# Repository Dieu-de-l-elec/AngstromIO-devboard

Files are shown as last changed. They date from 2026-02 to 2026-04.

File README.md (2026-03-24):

# AngstromIO-devboard

AngstromIO is one of the smallest devboards out there, barely longer than a USB-C connector, based on the Attiny1616 MCU. 2 GPIOs as well as I2C lines are broken out. 
I made a dual CH340 programming board too, both for UPDI programming and debugging (one way Serial Communication). 
I also designed a breadboard friendly, experimentation board for the CH32V003, with a 5x4 charlieplexed LED matrix.

While the AngstromIO is a tiny devboard, yet powerful, that could be embedded in any space constrained projects, the CH32 devboard is more an experimentation board, for me to learn how to program this awesome chip on the MounriverStudio programming and how to program a charlieplexed matrix. The Programmer is an all in one module, that will make debugging with the Serial monitor while programming easy: one board for both.

<br><br>
<p align="center">
  Project Banner
  AIO demo gif
</p>
<p align="center">
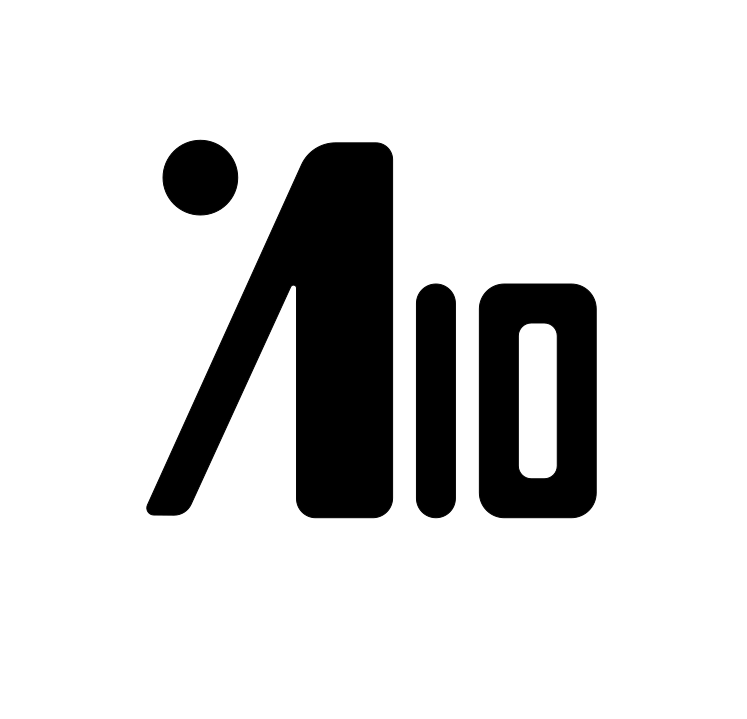
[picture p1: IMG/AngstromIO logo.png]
IOX-77 LOGO
   
  ALL demo gif
</p>
<br><br>

# Key features:
### AngstromIO Key features:
- One of the smallest devboards: 8.9mm by 9mm, USB-C included
- Attiny1616 MCU, 16Kb flash, low power, arduino compatible (for basic libraries at least)
- USB-C for power, runs at 5V
- 2x RGB addressable LEDs (SK6805-EC15)
- Pins broken out: SCL, SDA, PB2 (TX), PA3, +5V, GND, and UPDI for programming

### Programmer Key features:
- Dual CH340E setup:
    - One for programming (set as SerialUPDI programmer),
    - One for debugging (Serial Communication, USB to UART)
- 2 USB-C for data transfer, only the USB-C for Serial provides 5V to the board
- Onboard 3.3V LDO
- 3.3V/5V operating voltage selection

### CH32 devboard Key features:
- Breadboard friendly devboard
- cheap 25cents CH32V003, Risc-V MCU, 16Kb flash
- USB-C for power, the CH32 runs at 3.3V but PC6 and PC5 are 5V tolerant
- On board 3.3V LDO
- 4x5 charlieplexed LED matrix
- SWIO programming, proper programmer required (WCH linkE)

demo here: https://www.youtube.com/watch?v=cnP7mQc9vTc

# Pinout:

PINOUT AIO no frame
PINOUT CH32 no frame
PINOUT PGM no frame

# Software:
### AngstromIO Software:
Arduino compatible, some libraries may not work, but some have been arranged/made by SpenceKonde like Wire (I2C) and tinyNeoPixel (for more information, see: https://github.com/SpenceKonde/megaTinyCore/tree/master/megaavr/libraries)

(see `AIO_demo.ino`file under FIRMWARE/AngstromIO)

### CH32 devboard Software:
Programmed on the Mounriver studio IDE
(see `main.c`file under FIRMWARE/CH32 devboard)

# PCB design:
PCB designed in EasyEDA Pro, 2 layers, 1.0mm thick, Purple soldermask
All 3 designs panelized into one PCB.

# Schematic:
SCHEMATIC

# PCB Layout:

angstromIO 3d S3
angstromIO 3d S4
angstromIO 3d S6

panel front

panel back

Programmer PCB 2D
CH32 Devboard top
CH32 Devboard btm

Layout top panel
Layout bottom panel

# Renders:

Render AngstromIO devboard Top

Render AngstromIO devboard Bottom

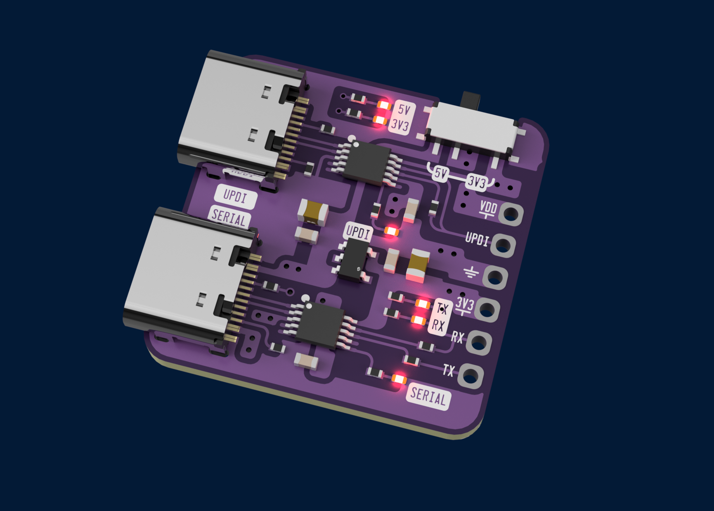
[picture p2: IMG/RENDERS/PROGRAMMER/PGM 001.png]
Render programmer 1

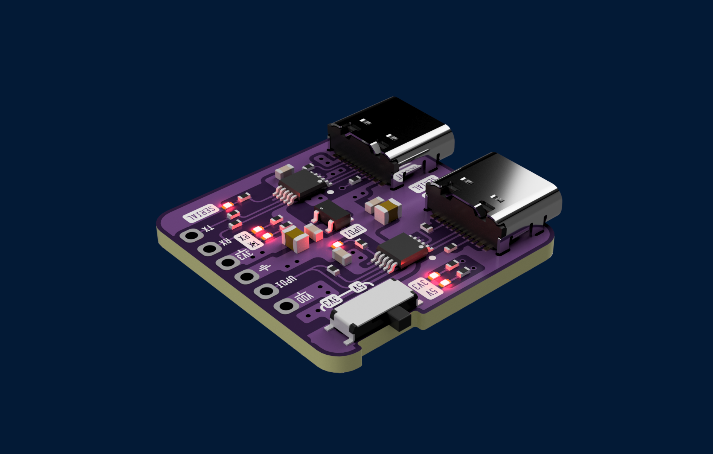
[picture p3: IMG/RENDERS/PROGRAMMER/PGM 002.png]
Render programmer 2

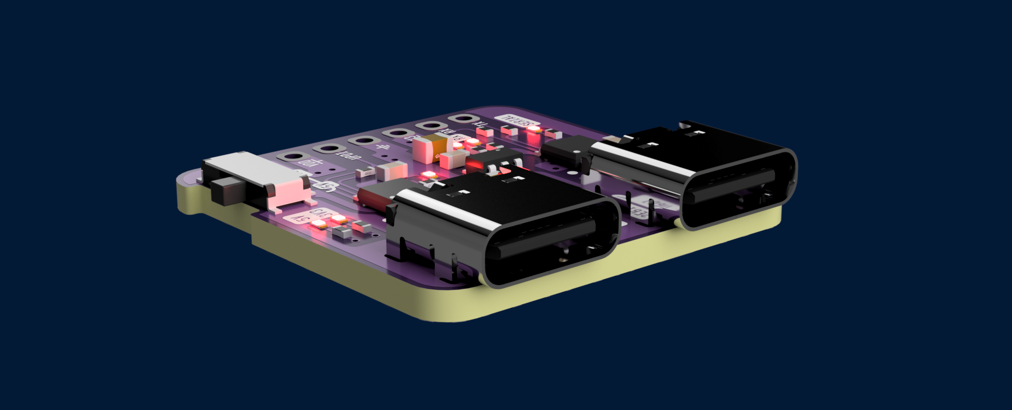
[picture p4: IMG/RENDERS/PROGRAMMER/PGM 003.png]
Render programmer 3

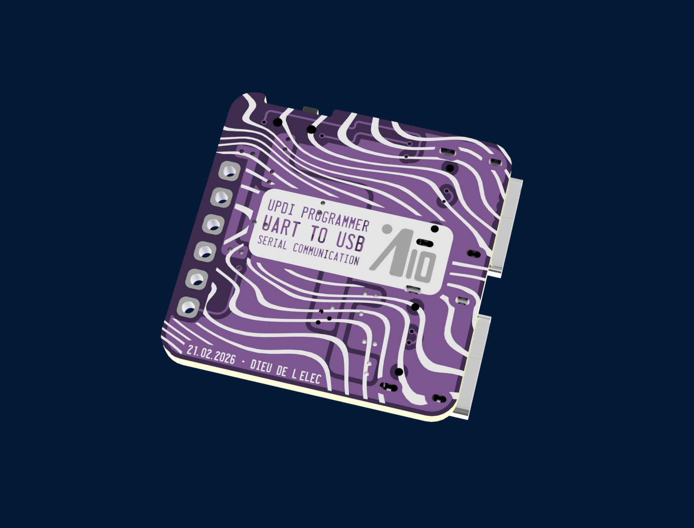
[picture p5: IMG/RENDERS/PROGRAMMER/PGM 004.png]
Render programmer 4


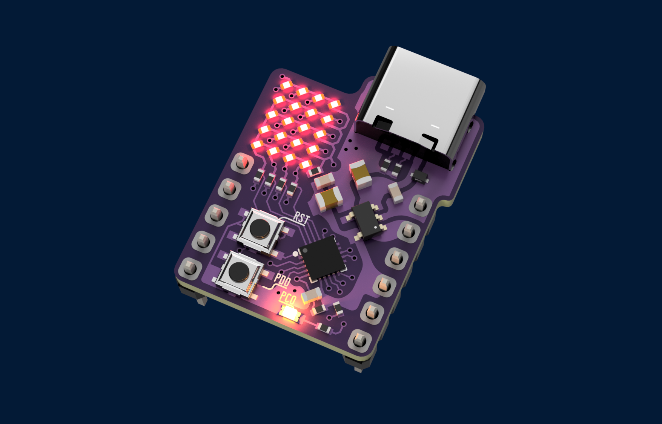
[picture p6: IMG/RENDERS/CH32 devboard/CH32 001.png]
Render CH32 devboard 1

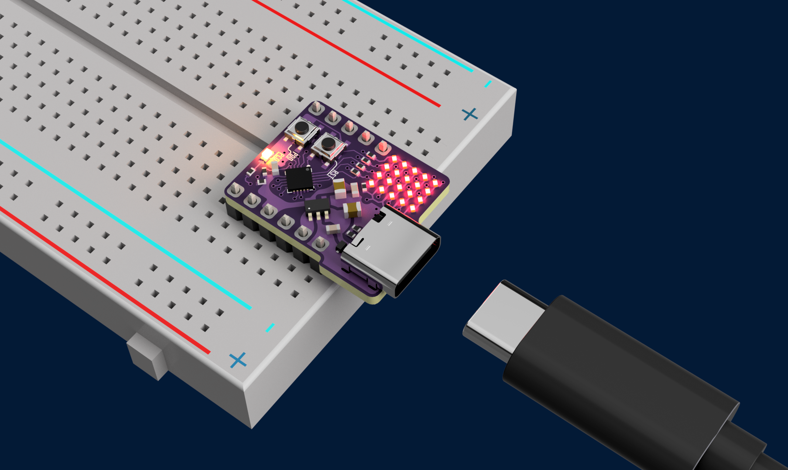
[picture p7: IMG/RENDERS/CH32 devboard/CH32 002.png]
Render CH32 devboard 2

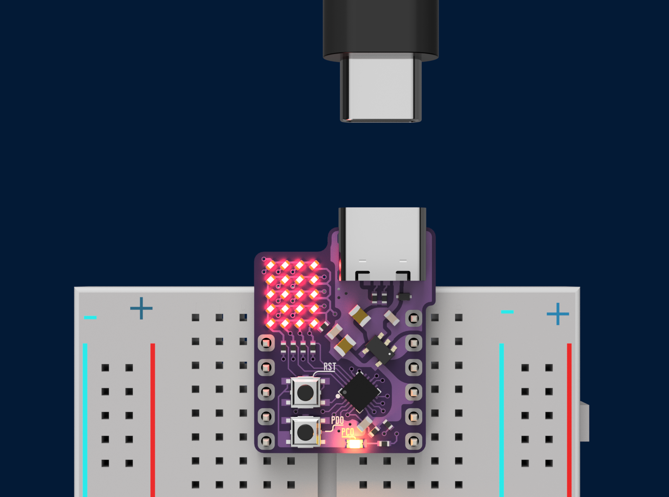
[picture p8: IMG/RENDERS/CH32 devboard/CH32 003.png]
Render CH32 devboard 3

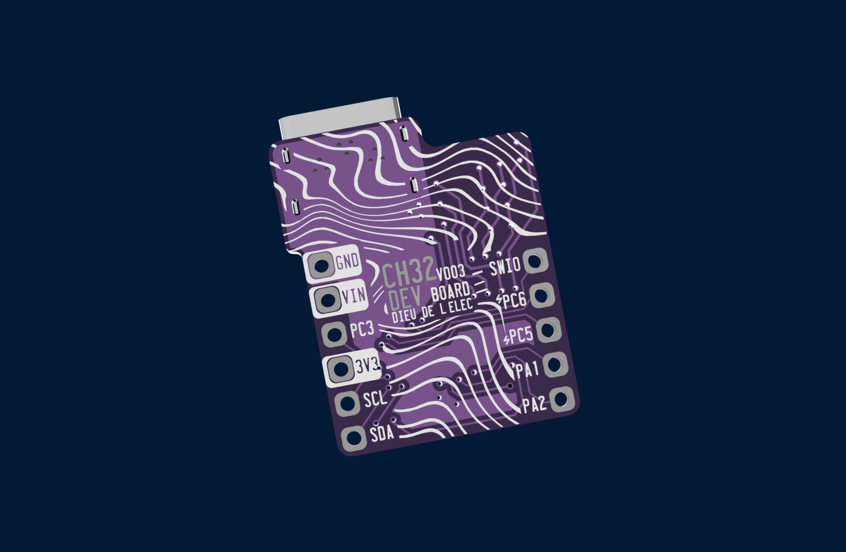
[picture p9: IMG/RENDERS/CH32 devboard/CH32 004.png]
Render CH32 devboard 4

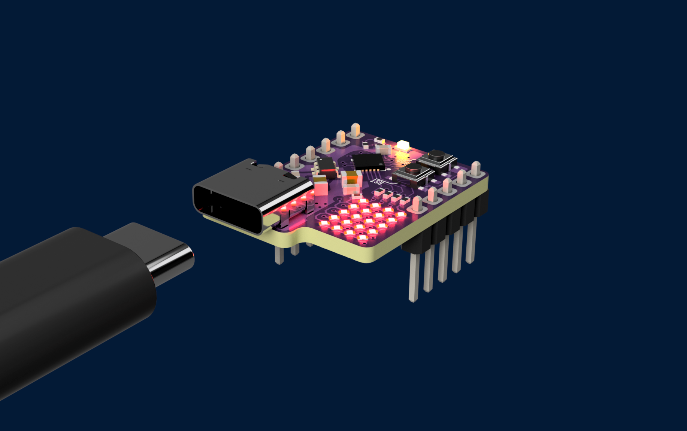
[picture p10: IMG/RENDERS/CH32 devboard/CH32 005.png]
Render CH32 devboard 5


# BUILD:

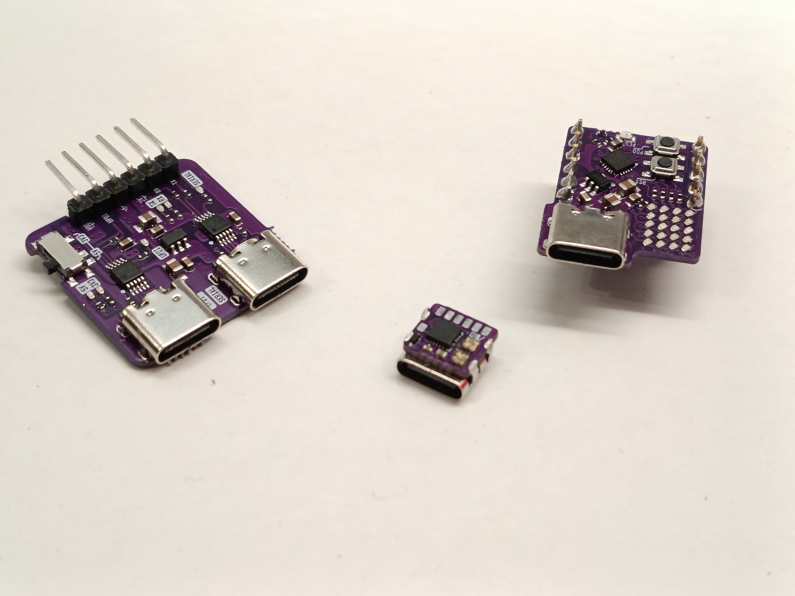
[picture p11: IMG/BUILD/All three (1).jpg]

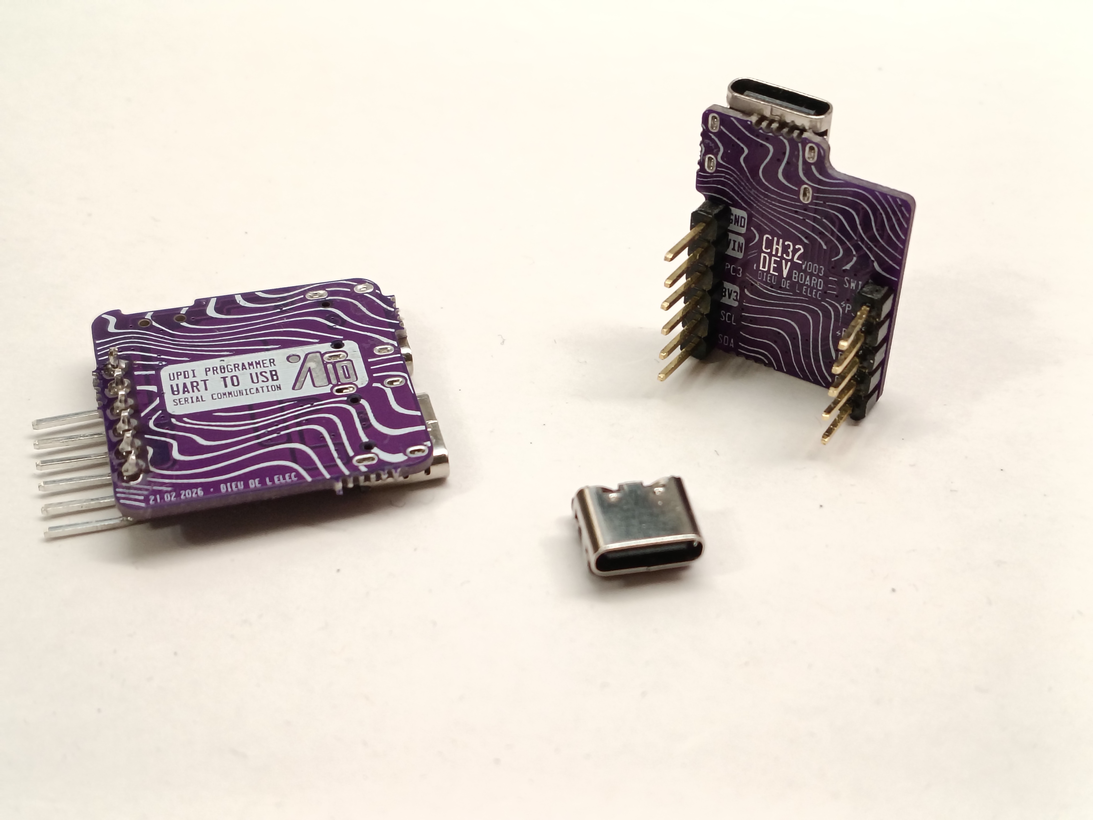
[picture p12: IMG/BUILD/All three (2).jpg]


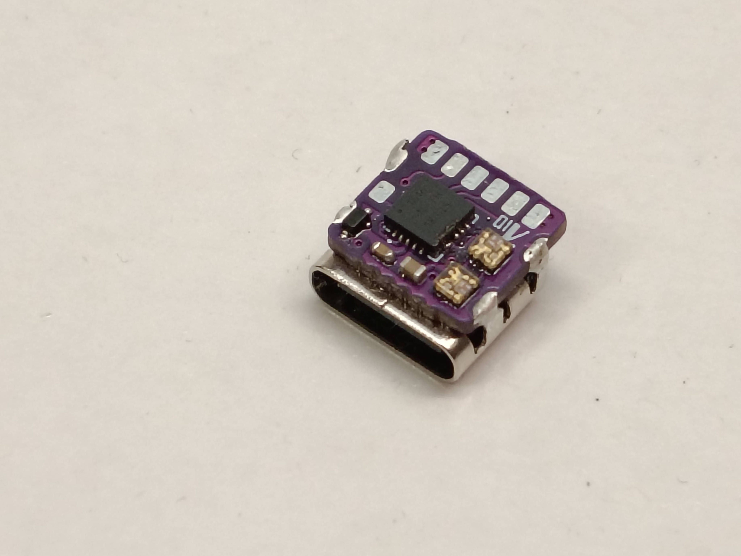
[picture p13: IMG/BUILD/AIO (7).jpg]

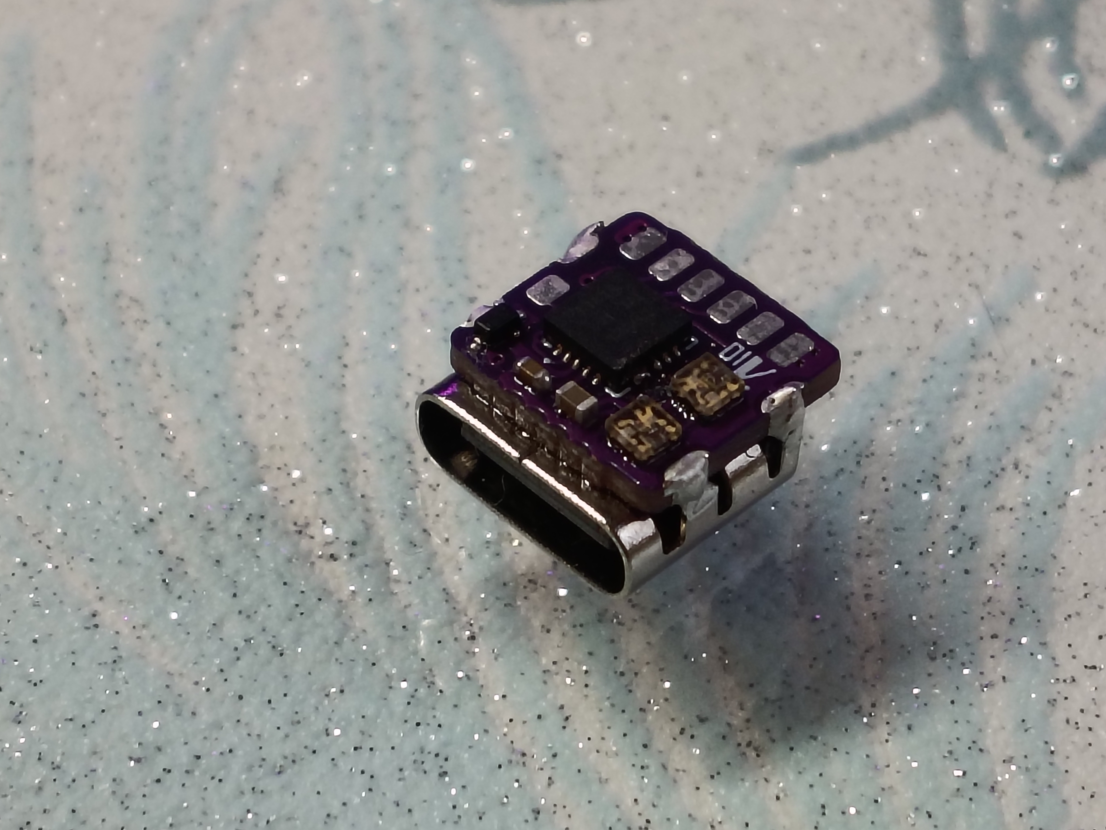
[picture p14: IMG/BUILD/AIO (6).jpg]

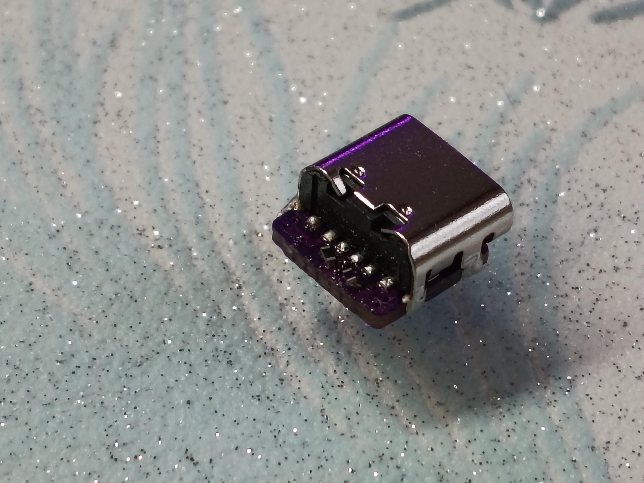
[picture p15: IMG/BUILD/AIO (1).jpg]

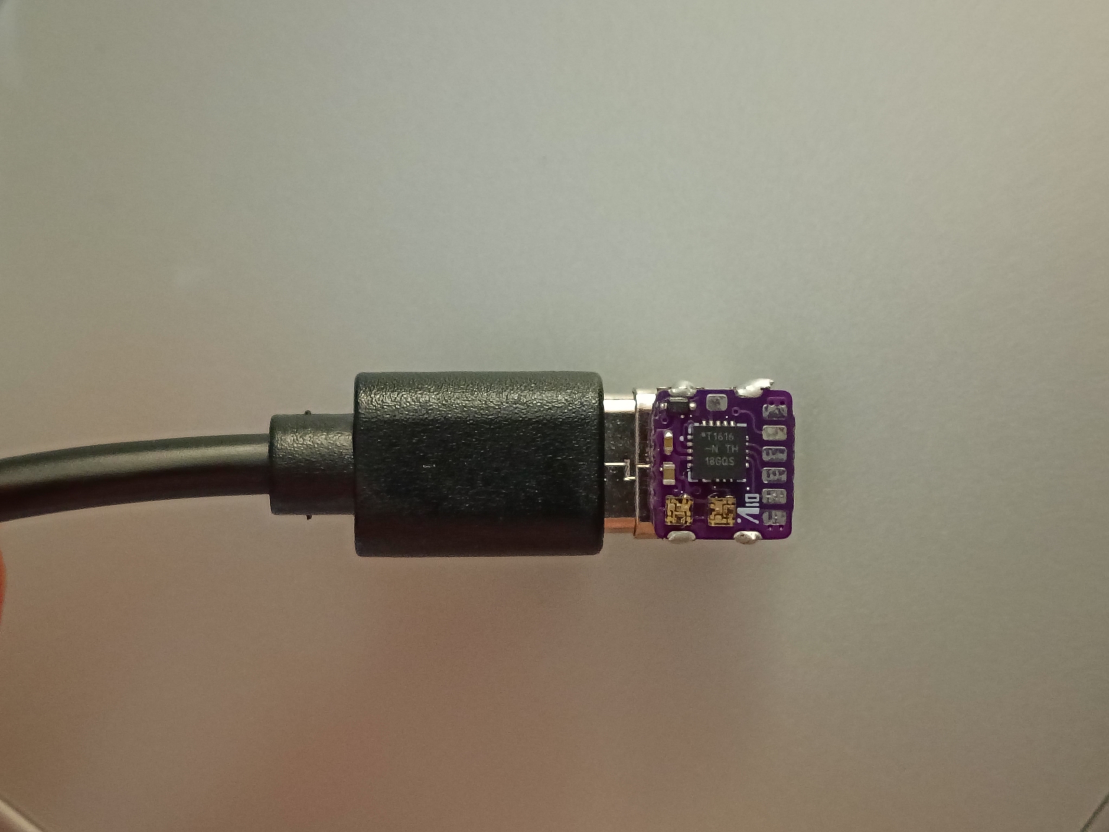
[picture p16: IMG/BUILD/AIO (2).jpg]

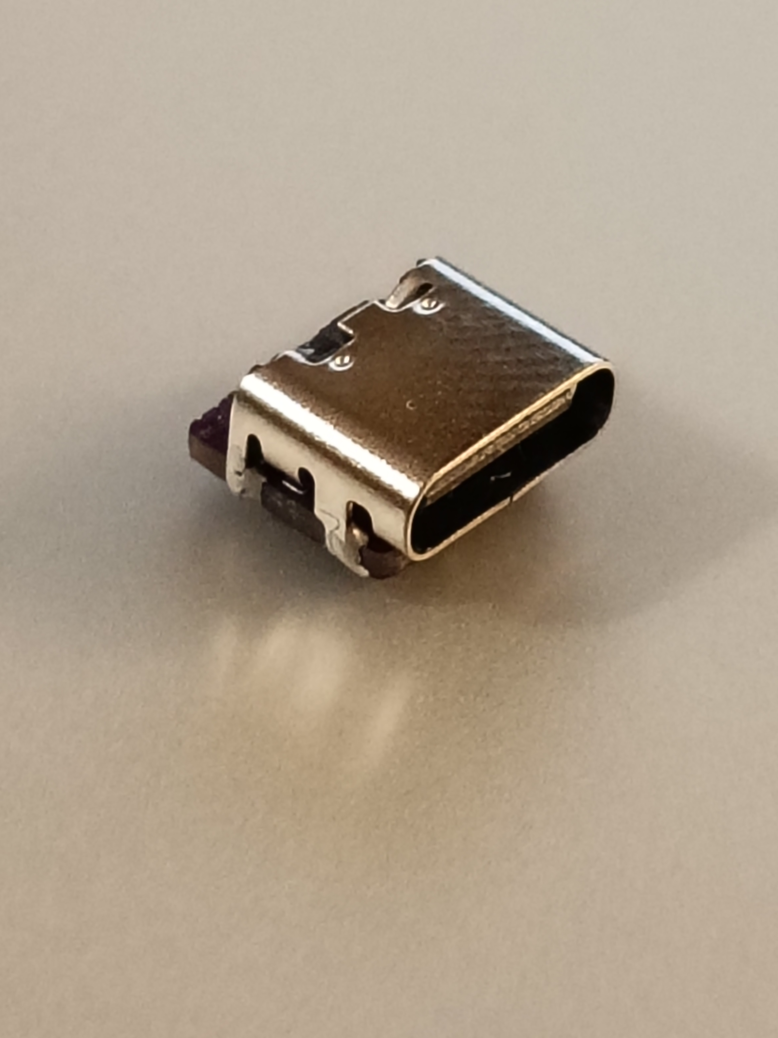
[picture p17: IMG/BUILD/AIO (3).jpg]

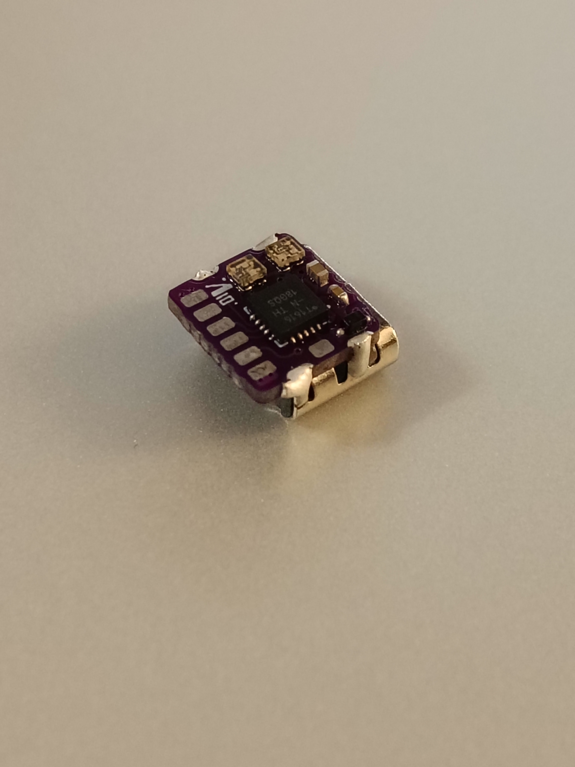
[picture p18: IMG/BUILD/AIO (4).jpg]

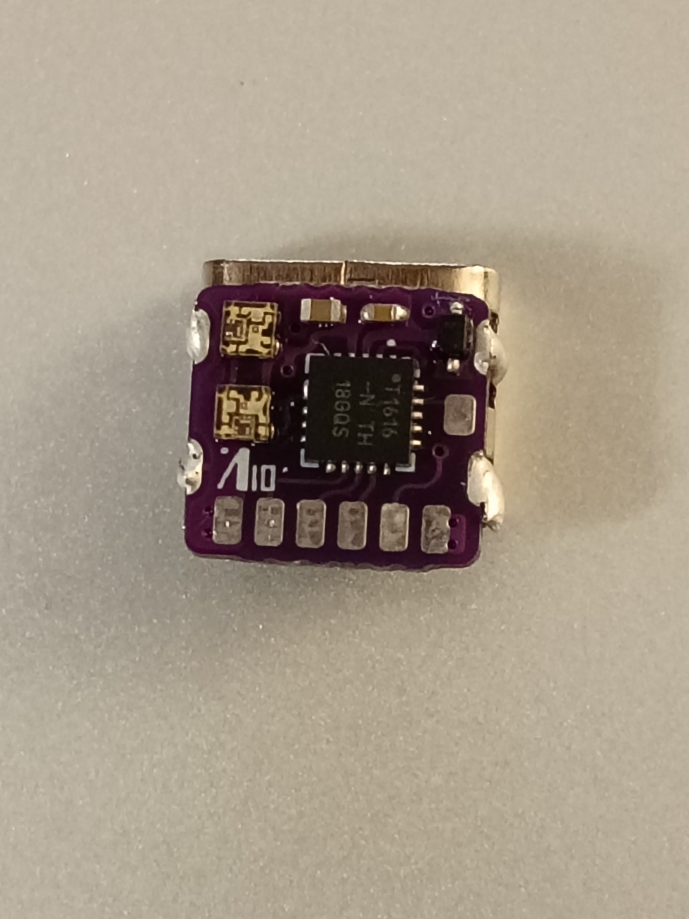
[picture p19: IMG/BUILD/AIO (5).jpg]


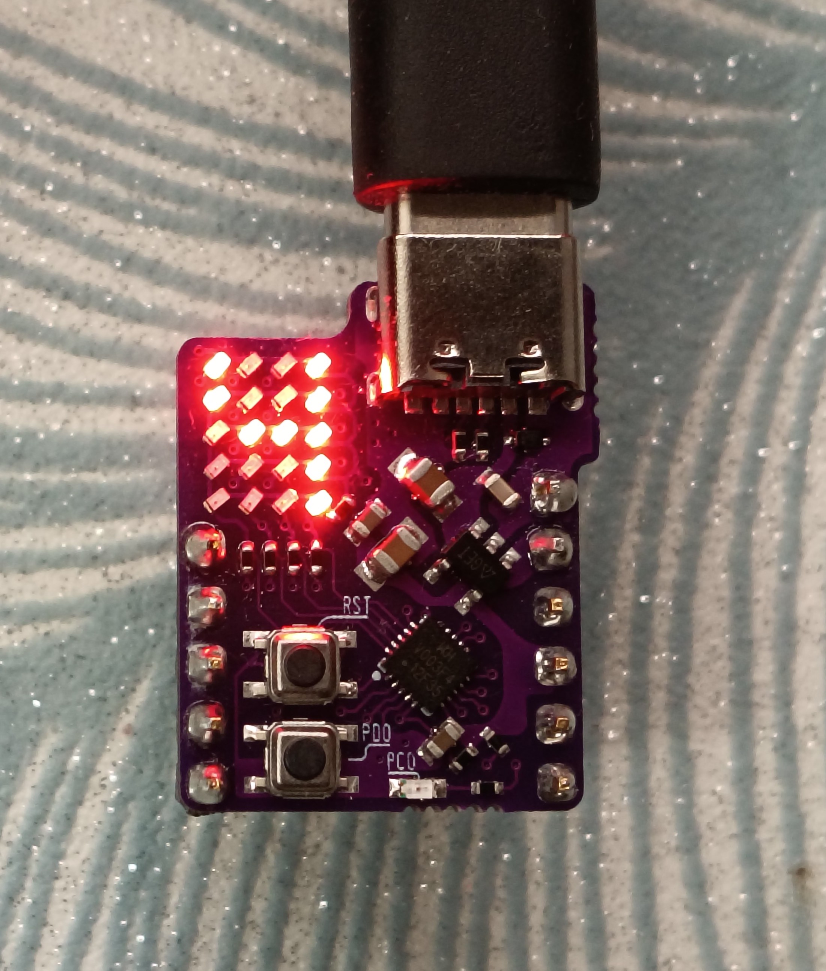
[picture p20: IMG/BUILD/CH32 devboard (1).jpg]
Render CH32 devboard 5

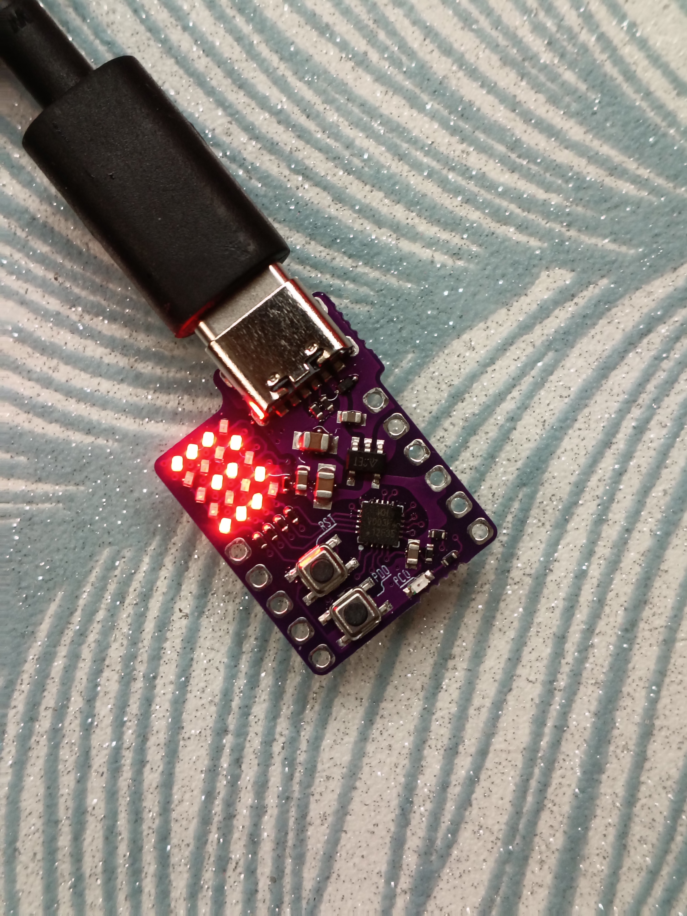
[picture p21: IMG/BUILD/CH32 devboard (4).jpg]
Render CH32 devboard 5

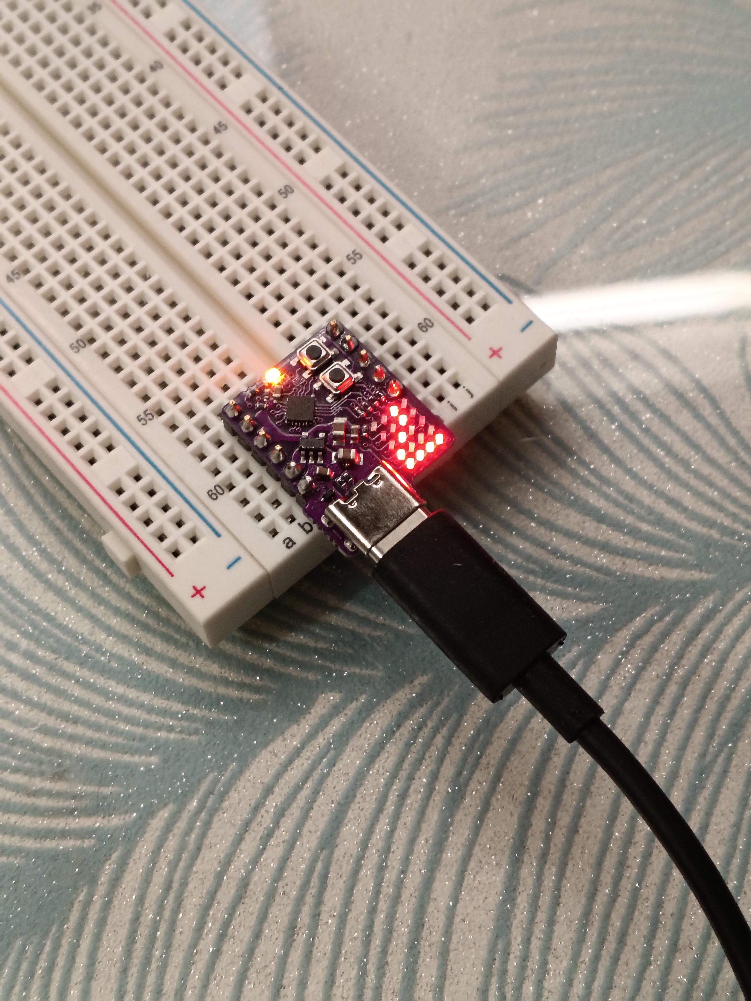
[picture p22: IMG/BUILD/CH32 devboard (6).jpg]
Render CH32 devboard 5

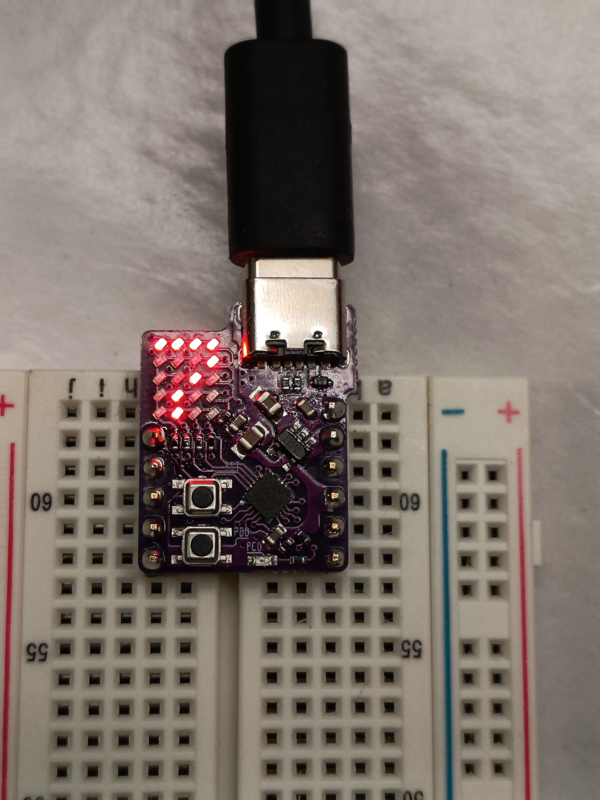
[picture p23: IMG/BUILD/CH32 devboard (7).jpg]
Render CH32 devboard 5

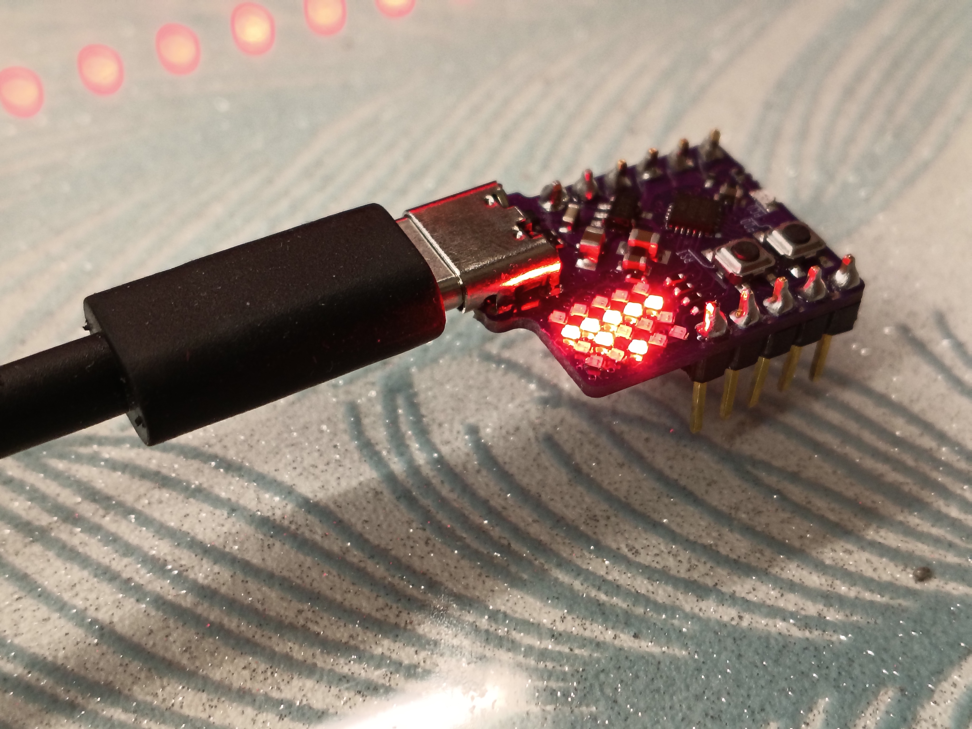
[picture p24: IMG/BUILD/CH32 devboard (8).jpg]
Render CH32 devboard 5


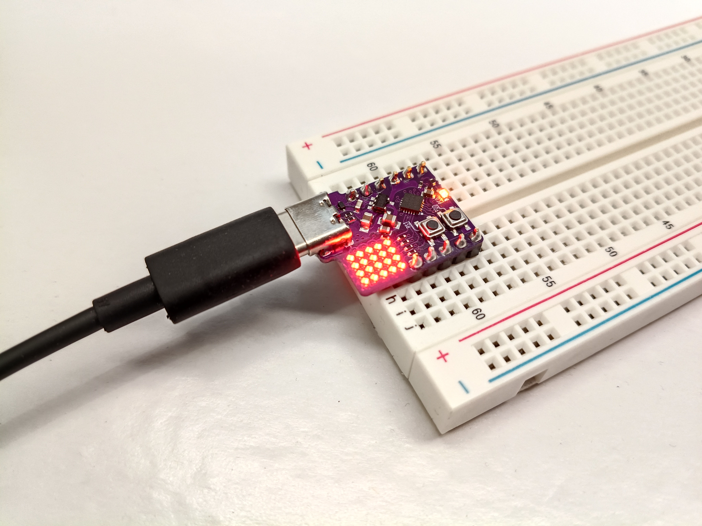
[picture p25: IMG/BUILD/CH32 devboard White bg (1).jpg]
Render CH32 devboard 5

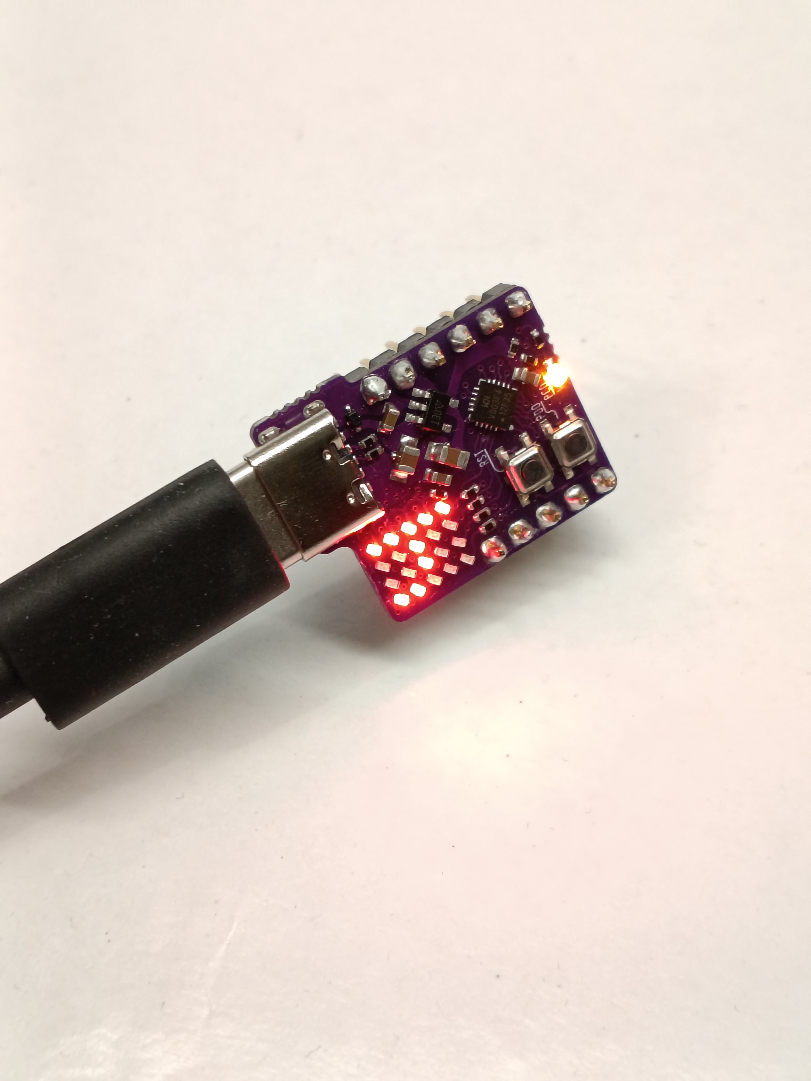
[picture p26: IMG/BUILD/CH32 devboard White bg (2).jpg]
Render CH32 devboard 5

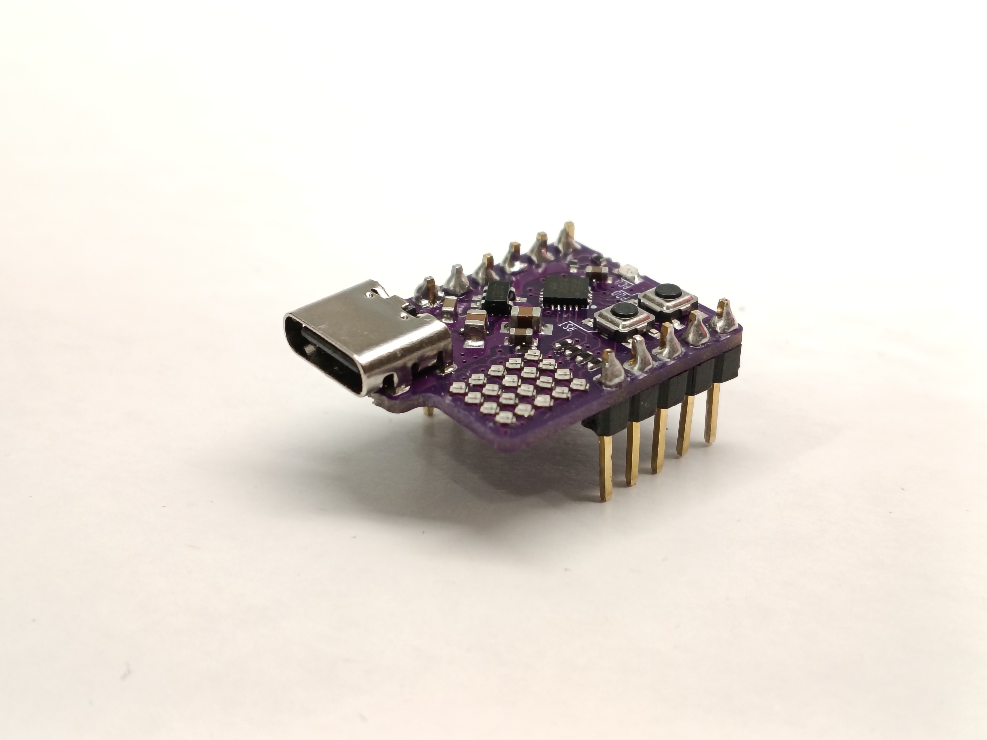
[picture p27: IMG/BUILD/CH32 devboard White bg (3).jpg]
Render CH32 devboard 5

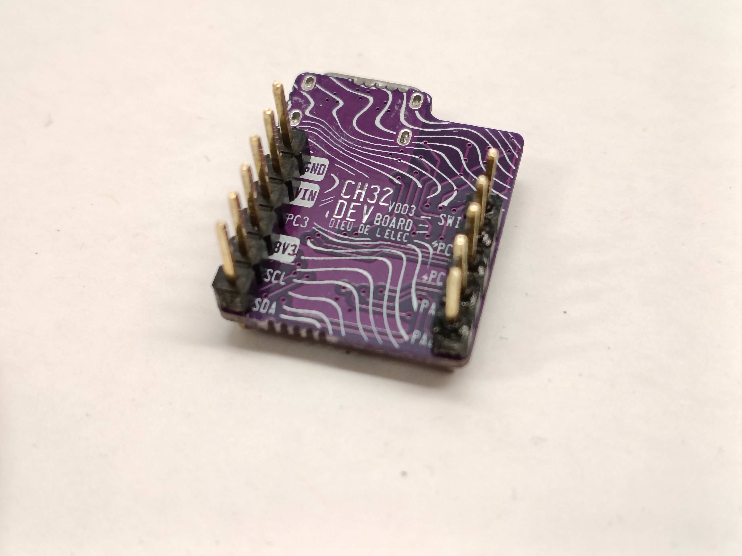
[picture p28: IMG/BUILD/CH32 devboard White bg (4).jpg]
Render CH32 devboard 5

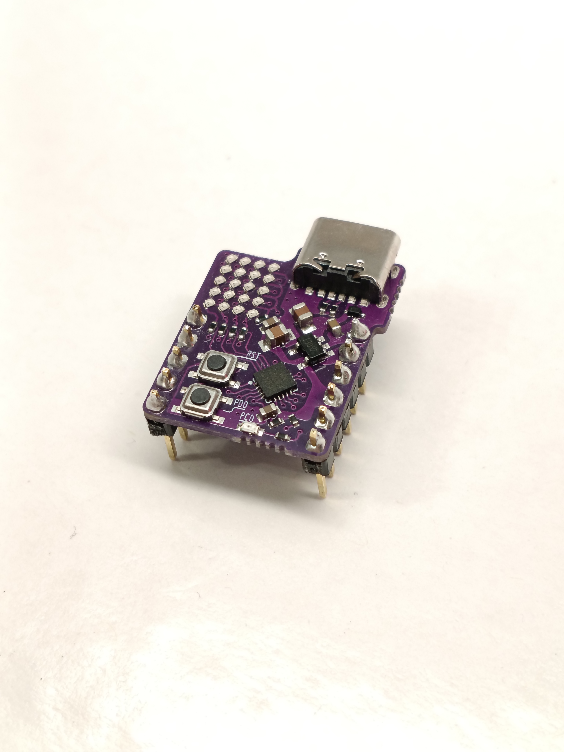
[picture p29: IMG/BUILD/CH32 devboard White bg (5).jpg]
Render CH32 devboard 5


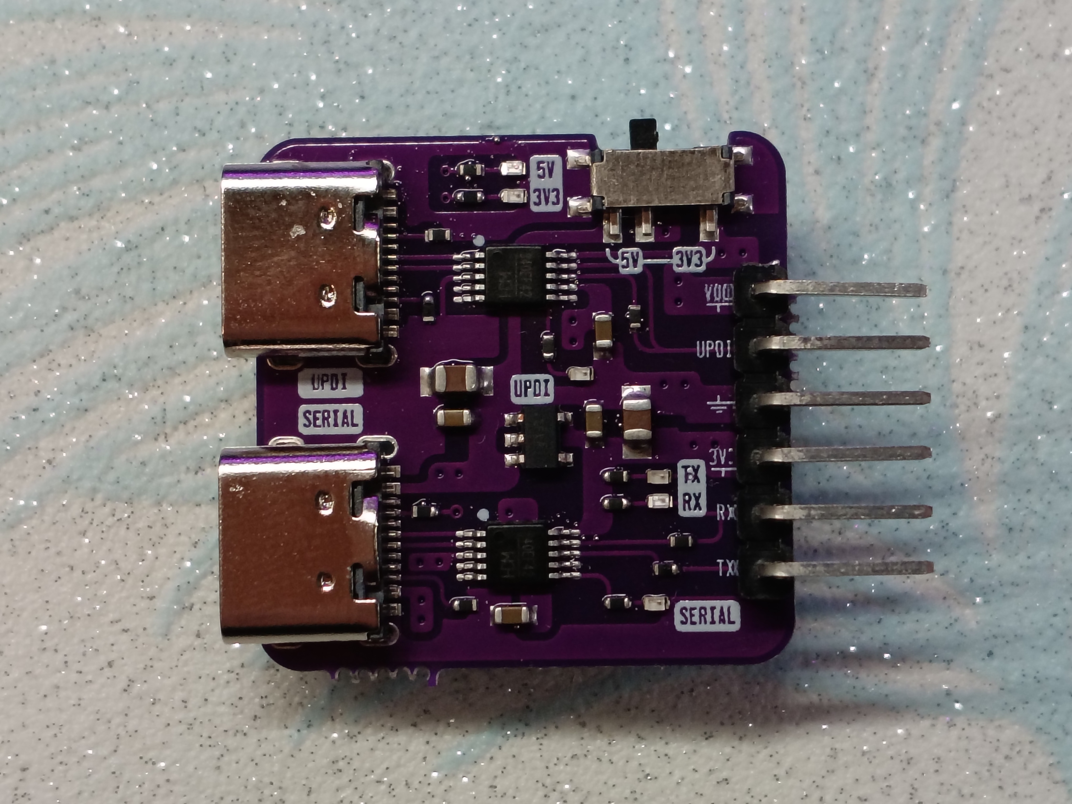
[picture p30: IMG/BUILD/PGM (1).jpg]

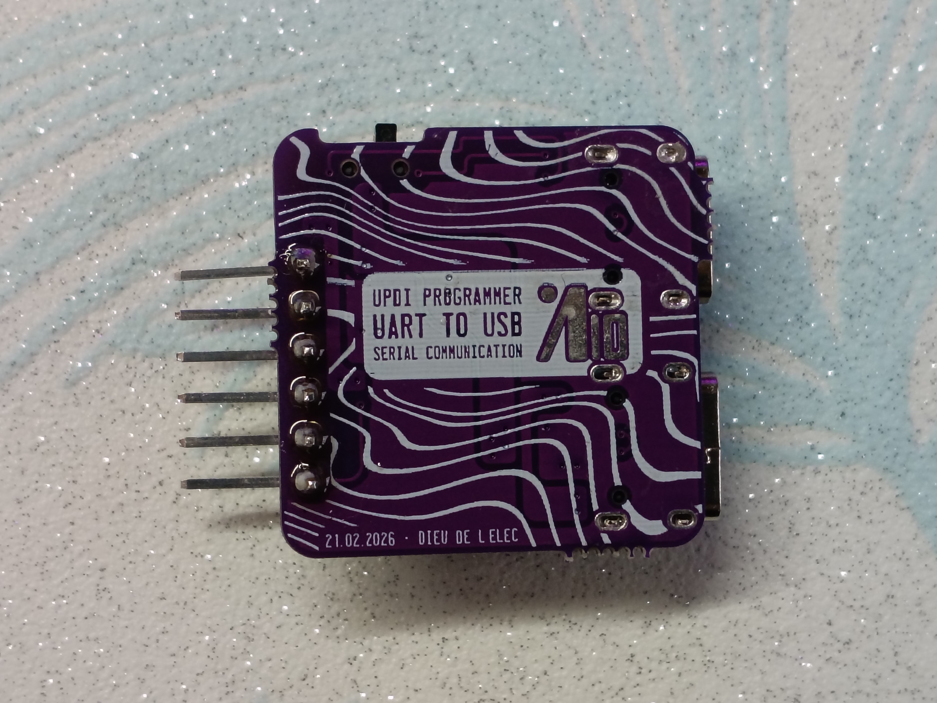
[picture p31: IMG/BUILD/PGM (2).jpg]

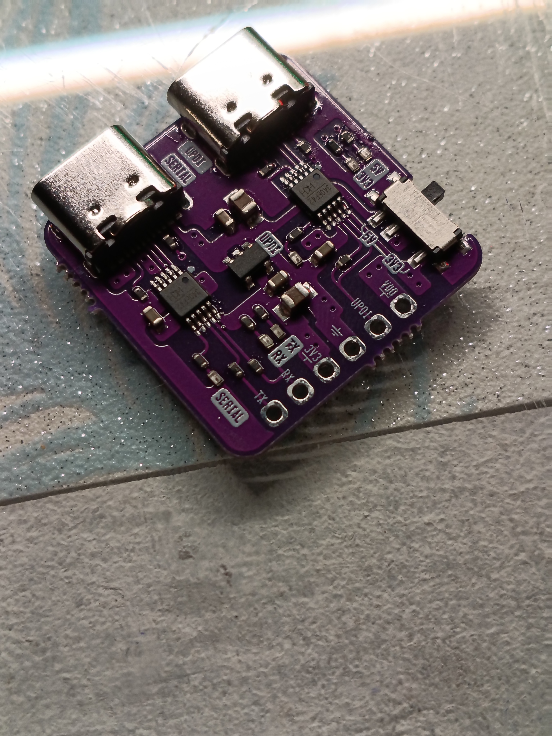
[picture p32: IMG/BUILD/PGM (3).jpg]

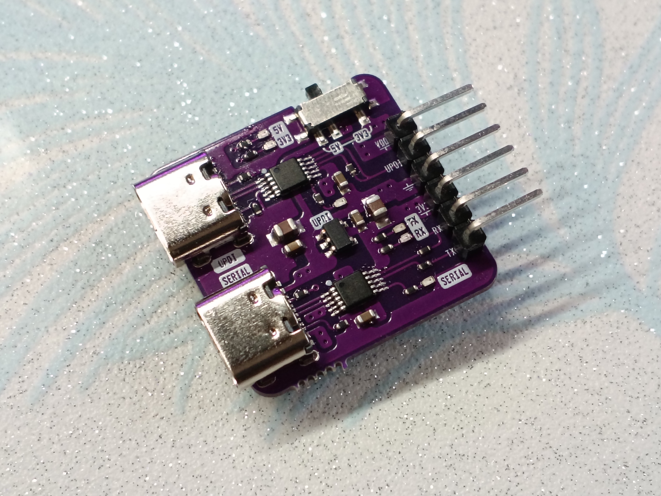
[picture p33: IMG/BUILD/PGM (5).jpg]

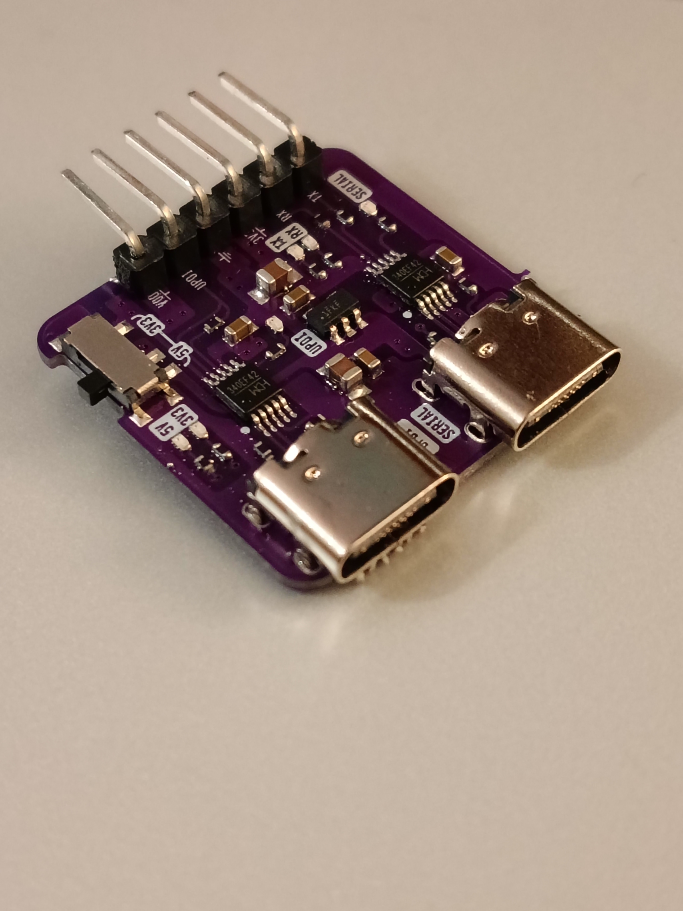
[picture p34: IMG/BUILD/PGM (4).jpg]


# BOM:

### AngstromIO BOM:
Qty| Part| Value| LCSC Part Number| Link
--- | --- | --- | --- | ---
 1| ATTINY1616-MNR| | C507118| https://www.lcsc.com/product-detail/C507118.html
 2| Resistor 0402| 5.1kΩ| C473460| https://www.lcsc.com/product-detail/C473460.html
 1| USB TYPE-C| 6P| C668623| https://www.lcsc.com/product-detail/C668623.html
 2| RGB addressable LED SK6805-EC15| | C2890035| https://www.lcsc.com/product-detail/C2890035.html
 1| MLCC Ceramic capacitor 0402| 100nF| C1525| https://www.lcsc.com/product-detail/C1525.html
 1| MLCC Ceramic capacitor 0402| 10µF| C315248| https://www.lcsc.com/product-detail/C315248.html
 1| TVS diode| | C5199850| https://www.lcsc.com/product-detail/C5199850.html
 1| | + Custom PCB Panel | | I used JLCPCB services https://jlcpcb.com

### Programmer BOM:
Qty| Part| Value| LCSC Part Number| Link
--- | --- | --- | --- | ---
 2| CH340E| | C99652|  https://www.lcsc.com/product-detail/C99652.html
 1| TLV75733PDBVR 3V3 LDO| | C485517| https://www.lcsc.com/product-detail/C485517.html
 1| Slide switch MK-12C02-G015| | C2911519| https://www.lcsc.com/product-detail/C2911519.html
 6| RED LED 0402| | C25503345| https://www.lcsc.com/product-detail/C25503345.html
 7| Resistor 0402| 5.1kΩ| C473460| https://www.lcsc.com/product-detail/C473460.html
 6| Resistor 0402| 1kΩ| C2906864| https://www.lcsc.com/product-detail/C2906864.html
 2| MLCC Ceramic capacitor 0805| 10µF| C15850| https://www.lcsc.com/product-detail/C15850.html
 4| MLCC Ceramic capacitor 0603| 100nF| C66501| https://www.lcsc.com/product-detail/C66501.html
 2| USB TYPE-C| 16P| C2765186| https://www.lcsc.com/product-detail/C2765186.html
 1| 2.54 Dupont headers| 6P| C492414| https://www.lcsc.com/product-detail/C492414.html
 1| | + Custom PCB Panel | | I used JLCPCB services https://jlcpcb.com
 
### CH32 devboard BOM:
Qty| Part| Value| LCSC Part Number| Link
--- | --- | --- | --- | ---
 1| USB TYPE-C| 6P| C668623| https://www.lcsc.com/product-detail/C668623.html
 2| Resistor 0402| 5.1kΩ| C473460| https://www.lcsc.com/product-detail/C473460.html
 1| Resistor 0402| 1kΩ| C2906864| https://www.lcsc.com/product-detail/C2906864.html
 2| Resistor 0402| 10kΩ| C2906861| https://www.lcsc.com/product-detail/C2906861.html
 5| Resistor 0402| 680Ω| C2909378| https://www.lcsc.com/product-detail/C2909378.html
 2| MLCC Ceramic capacitor 0805| 10µF| C15850| https://www.lcsc.com/product-detail/C15850.html
 3| MLCC Ceramic capacitor 0603| 100nF| C66501| https://www.lcsc.com/product-detail/C66501.html
 1| TVS diode|| C5199850| https://www.lcsc.com/product-detail/C5199850.html
 20| RED LED 0402| | C25503345| https://www.lcsc.com/product-detail/C25503345.html
 2| tactile switch| | C492872| https://www.lcsc.com/product-detail/C492872.html
 1| Orange LED 0603| | C965800| https://www.lcsc.com/product-detail/C965800.html
 1| CH32V003F4U6| | C5299908| https://www.lcsc.com/product-detail/C5299908.html
 1| AP2127K-3.3TRG1 3V3 LDO| | C156285| https://www.lcsc.com/product-detail/C156285.html
 1| 2.54 Dupont headers| 5P| C42431794| https://www.lcsc.com/product-detail/C42431794.html
 1| 2.54 Dupont headers| 6P| C42431807| https://www.lcsc.com/product-detail/C42431807.html
 1| | + Custom PCB Panel|  | I used JLCPCB services https://jlcpcb.com

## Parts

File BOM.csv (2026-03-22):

BOARD | Qty | Part | Value | LCSC Part Number | Link
AIO | 1 | ATTINY1616-MNR |  | C507118 | https://www.lcsc.com/product-detail/C507118.html
AIO | 2 | Resistor 0402 | 5.1kΩ | C473460 | https://www.lcsc.com/product-detail/C473460.html
AIO | 1 | USB TYPE-C | 6P | C668623 | https://www.lcsc.com/product-detail/C668623.html
AIO | 2 | RGB addressable LED SK6805-EC15 |  | C2890035 | https://www.lcsc.com/product-detail/C2890035.html
AIO | 1 | MLCC Ceramic capacitor 0402 | 100nF | C1525 | https://www.lcsc.com/product-detail/C1525.html
AIO | 1 | MLCC Ceramic capacitor 0402 | 10µF | C315248 | https://www.lcsc.com/product-detail/C315248.html
AIO | 1 | TVS diode |  | C5199850 | https://www.lcsc.com/product-detail/C5199850.html
-
PGM | 2 | CH340E |  | C99652 | https://www.lcsc.com/product-detail/C99652.html
PGM | 1 | TLV75733PDBVR 3V3 LDO |  | C485517 | https://www.lcsc.com/product-detail/C485517.html
PGM | 1 | Slide switch MK-12C02-G015 |  | C2911519 | https://www.lcsc.com/product-detail/C2911519.html
PGM | 6 | RED LED 0402 |  | C25503345 | https://www.lcsc.com/product-detail/C25503345.html
PGM | 7 | Resistor 0402 | 5.1kΩ | C473460 | https://www.lcsc.com/product-detail/C473460.html
PGM | 6 | Resistor 0402 | 1kΩ | C2906864 | https://www.lcsc.com/product-detail/C2906864.html
PGM | 2 | MLCC Ceramic capacitor 0805 | 10µF | C15850 | https://www.lcsc.com/product-detail/C15850.html
PGM | 4 | MLCC Ceramic capacitor 0603 | 100nF | C66501 | https://www.lcsc.com/product-detail/C66501.html
PGM | 2 | USB TYPE-C | 16P | C2765186 | https://www.lcsc.com/product-detail/C2765186.html
PGM | 1 | 2.54 Dupont headers | 6P | C492414 | https://www.lcsc.com/product-detail/C492414.html
-
CH32 dev. | 1 | USB TYPE-C | 6P | C668623 | https://www.lcsc.com/product-detail/C668623.html
CH32 dev. | 2 | Resistor 0402 | 5.1kΩ | C473460 | https://www.lcsc.com/product-detail/C473460.html
CH32 dev. | 1 | Resistor 0402 | 1kΩ | C2906864 | https://www.lcsc.com/product-detail/C2906864.html
CH32 dev. | 2 | Resistor 0402 | 10kΩ | C2906861 | https://www.lcsc.com/product-detail/C2906861.html
CH32 dev. | 5 | Resistor 0402 | 680Ω | C2909378 | https://www.lcsc.com/product-detail/C2909378.html
CH32 dev. | 2 | MLCC Ceramic capacitor 0805 | 10µF | C15850 | https://www.lcsc.com/product-detail/C15850.html
CH32 dev. | 3 | MLCC Ceramic capacitor 0603 | 100nF | C66501 | https://www.lcsc.com/product-detail/C66501.html
CH32 dev. | 1 | TVS diode |  | C5199850 | https://www.lcsc.com/product-detail/C5199850.html
CH32 dev. | 20 | RED LED 0402 |  | C25503345 | https://www.lcsc.com/product-detail/C25503345.html
CH32 dev. | 2 | tactile switch |  | C492872 | https://www.lcsc.com/product-detail/C492872.html
CH32 dev. | 1 | Orange LED 0603 |  | C965800 | https://www.lcsc.com/product-detail/C965800.html
CH32 dev. | 1 | CH32V003F4U6 |  | C5299908 | https://www.lcsc.com/product-detail/C5299908.html
CH32 dev. | 1 | AP2127K-3.3TRG1 3V3 LDO |  | C156285 | https://www.lcsc.com/product-detail/C156285.html
CH32 dev. | 1 | 2.54 Dupont headers | 5P | C42431794 | https://www.lcsc.com/product-detail/C42431794.html
CH32 dev. | 1 | 2.54 Dupont headers | 6P | C42431807 | https://www.lcsc.com/product-detail/C42431807.html
ALL |  | + Custom PCB Panel |  |  | I used JLCPCB services https://jlcpcb.com

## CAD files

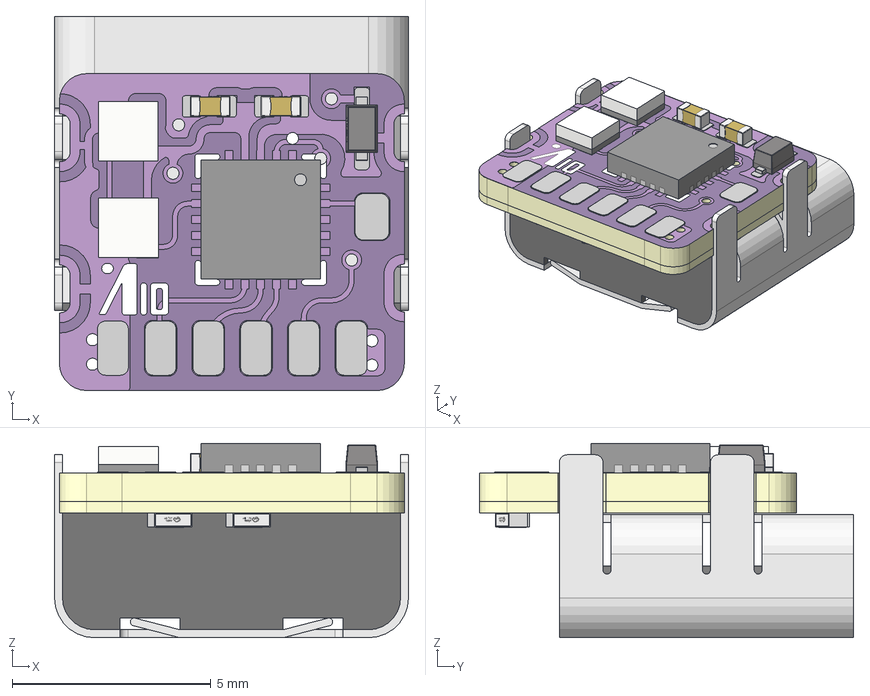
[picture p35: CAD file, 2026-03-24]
CAD/angstromIO_3D.step
8.90 x 9.41 x 4.89 mm
Board~XlWg
TopCopper~XlWg
BottomCopper~XlWg
TopSilkscreen~XlWg
LED-SMD_4P-L1.5-W1.5-BL~LED-SMD_4P-L1.5-W1.5-BL~XlWg x 2
C0402~C0402_L1.0-W0.5-H0.5~XlWg x 2
QFN-20_L3.0-W3.0-P0.40-BL-EP1.7~QFN-20_L3.0-W3.0-P0.40-BL-EP1.7~XlWg
SOD-523_L1.2-W0.8-LS1.6-BI~SOD-523_L1.2-W0.8-LS1.6-BI~XlWg
thinner 0402~R0402_L1.0-W0.5-H0.4~XlWg x 2
TypC Port

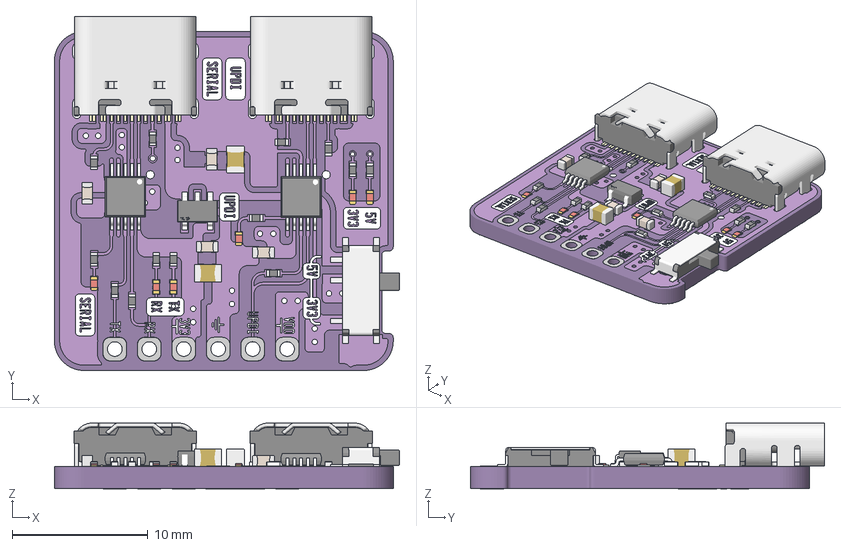
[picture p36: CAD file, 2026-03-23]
CAD/programmer_3D.3mf
25.4 x 26.1 x 4.86 mm
Corps1 x 66
Corps10 x 8
Corps11 x 8
Corps12 x 8
Corps13 x 8
Corps14 x 8
Corps15 x 6
Corps16 x 6
Corps17 x 5
Corps18 x 5
Corps19 x 5
Corps2 x 27
Corps20 x 3
Corps21 x 3
Corps22 x 3
Corps23 x 3
Corps24 x 3
Corps25 x 3
Corps26 x 3
Corps27 x 3
Corps28 x 3
Corps29 x 3
Corps3 x 27
Corps30 x 3
Corps31 x 3
Corps32 x 3
Corps33 x 3
Corps34 x 3
Corps35 x 3
Corps36 x 3
Corps37 x 3
Corps38 x 2
Corps39 x 2
Corps4 x 8
Corps40 x 2
Corps41 x 2
Corps42 x 2
Corps43 x 2
Corps44 x 2
Corps45 x 2
Corps46 x 2
Corps47 x 2
Corps48 x 2
Corps49 x 2
Corps5 x 8
Corps50 x 2
Corps51
Corps52
Corps53
Corps54
Corps55
Corps56
Corps57
Corps58
Corps59
Corps6 x 8
Corps60
Corps61
Corps62
Corps63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

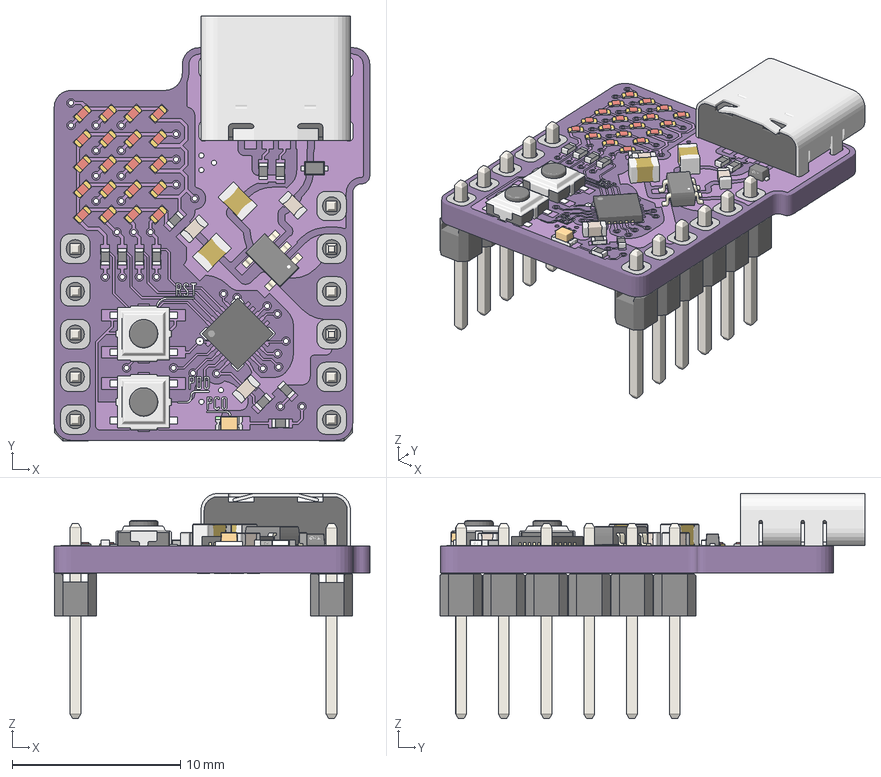
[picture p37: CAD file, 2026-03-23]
CAD/CH32_devboard.3mf
18.8 x 25.3 x 13.4 mm
Corps1 x 57
Corps10 x 6
Corps11 x 6
Corps12 x 6
Corps13 x 6
Corps14 x 6
Corps15 x 6
Corps16 x 6
Corps17 x 6
Corps18 x 6
Corps19 x 6
Corps2 x 43
Corps20 x 6
Corps21 x 6
Corps22 x 5
Corps23 x 4
Corps24 x 4
Corps25 x 4
Corps26 x 4
Corps27 x 4
Corps28 x 4
Corps29 x 4
Corps3 x 43
Corps30 x 3
Corps31 x 3
Corps32 x 3
Corps33 x 3
Corps34 x 3
Corps35 x 3
Corps36 x 3
Corps37 x 3
Corps38 x 3
Corps39 x 3
Corps4 x 11
Corps40 x 3
Corps41 x 3
Corps42 x 2
Corps43 x 2
Corps44 x 2
Corps45 x 2
Corps46 x 2
Corps47 x 2
Corps48 x 2
Corps49 x 2
Corps5 x 10
Corps50 x 2
Corps51 x 2
Corps52 x 2
Corps53 x 2
Corps54 x 2
Corps55 x 2
Corps56 x 2
Corps57 x 2
Corps58 x 2
Corps59 x 2
Corps6 x 10
Corps60 x 2
Corps61
Corps62
Corps63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

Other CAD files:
CAD/angstromIO_3D.3mf
CAD/angstromIO_3D_FUSION360.f3z

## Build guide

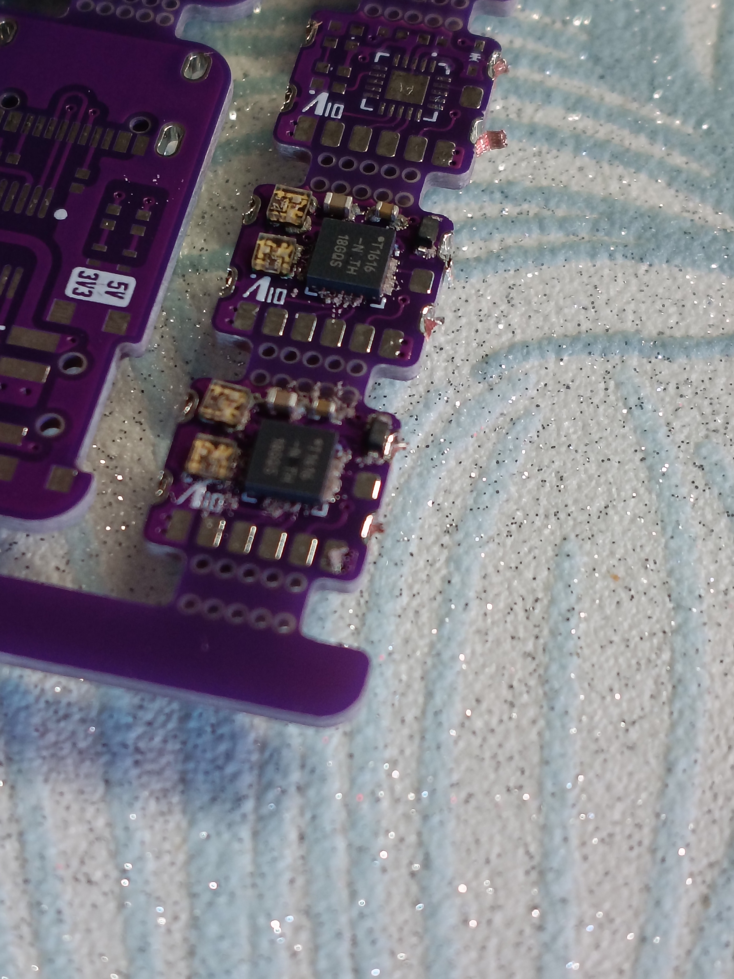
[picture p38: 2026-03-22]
IMG/BUILD/PCB Assembly 1.jpg

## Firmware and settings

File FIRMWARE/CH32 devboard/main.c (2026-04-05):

/*
 *   CH32 devboard demo code | by C.G. | https://github.com/Dieu-de-l-elec/AngstromIO-devboard/tree/main
 *   Charlieplexed 5x4 LED matrix
 *   1 button & 1 LED
 *   
 *   After creating a new Mounriver Studio project and selecting the chip 'CH32V003F4U', the following main.c file can be replaced with the following code (in User>main.c)  
 *   as the devboard doesn't comes with an external oscillator, the file 'system_ch32v00x.c has to be modified, changing the code as below:
 *            //#define SYSCLK_FREQ_8MHz_HSI    8000000
 *            //#define SYSCLK_FREQ_24MHZ_HSI   HSI_VALUE
 *            #define SYSCLK_FREQ_48MHZ_HSI   48000000               // This line has to be uncommented
 *            //#define SYSCLK_FREQ_8MHz_HSE    8000000
 *            //#define SYSCLK_FREQ_24MHz_HSE   HSE_VALUE
 *            //#define SYSCLK_FREQ_48MHz_HSE   48000000              Default line that should be commented
 */

#include "debug.h"

#define BUTTON_PIN 13
#define LED_PIN 7

uint32_t DELAY_FRAME = 2;  // 2 ms
uint8_t stateLED = 0;

typedef struct {
    GPIO_TypeDef *PORT;
    uint16_t PIN;
} PinSetup;

PinSetup pinMap[] = {

    {GPIOD, GPIO_Pin_6}, //  0  L1
    {GPIOD, GPIO_Pin_5}, //  1  L2
    {GPIOD, GPIO_Pin_4}, //  2  L3
    {GPIOD, GPIO_Pin_3}, //  3  L4
    {GPIOD, GPIO_Pin_2}, //  4   L5

    {GPIOA, GPIO_Pin_1}, //  5  T1CH2
    {GPIOA, GPIO_Pin_2}, //  6
    {GPIOC, GPIO_Pin_0}, //  7  T2CH3
    {GPIOC, GPIO_Pin_3}, //  8  T1CH3
    {GPIOC, GPIO_Pin_4}, //  9  T1CH4
    {GPIOC, GPIO_Pin_5}, //  10
    {GPIOC, GPIO_Pin_6}, //  11
    {GPIOC, GPIO_Pin_7}, //  12
    {GPIOD, GPIO_Pin_0}, //  13            Button here
    {GPIOC, GPIO_Pin_1}, //  14  SDA
    {GPIOC, GPIO_Pin_2}  //  15  SCL
};

static const uint8_t Off_LED_Matrix[5][4] = {
    {0, 0, 0, 0},
    {0, 0, 0, 0},
    {0, 0, 0, 0},
    {0, 0, 0, 0},
    {0, 0, 0, 0}
};

static const uint8_t On_LED_Matrix[5][4] = {
    {1, 1, 1, 1},
    {1, 1, 1, 1},
    {1, 1, 1, 1},
    {1, 1, 1, 1},
    {1, 1, 1, 1}
};

static const uint8_t Digits_Matrix[10][5][4] = {     // creating all the digits from 0 to 9
    {{0, 1, 1, 0},
     {1, 0, 0, 1},
     {1, 0, 0, 1},
     {1, 0, 0, 1},
     {0, 1, 1, 0}},

    {{0, 0, 1, 0},
     {0, 1, 1, 0},
     {1, 0, 1, 0},
     {0, 0, 1, 0},
     {0, 0, 1, 0}},

    {{1, 1, 1, 0},
     {0, 0, 0, 1},
     {0, 1, 1, 1},
     {1, 0, 0, 0},
     {1, 1, 1, 1}},

    {{1, 1, 1, 0},
     {0, 0, 0, 1},
     {0, 1, 1, 0},
     {0, 0, 0, 1},
     {1, 1, 1, 0}},

    {{1, 0, 0, 1},
     {1, 0, 0, 1},
     {0, 1, 1, 1},
     {0, 0, 0, 1},
     {0, 0, 0, 1}},

    {{1, 1, 1, 1},
     {1, 0, 0, 0},
     {1, 1, 1, 0},
     {0, 0, 0, 1},
     {1, 1, 1, 0}},

    {{0, 1, 1, 1},
     {1, 0, 0, 0},
     {1, 1, 1, 1},
     {1, 0, 0, 1},
     {0, 1, 1, 0}},

    {{1, 1, 1, 1},
     {0, 0, 0, 1},
     {0, 0, 1, 0},
     {0, 1, 0, 0},
     {0, 1, 0, 0}},

    {{0, 1, 1, 0},
     {1, 0, 0, 1},
     {0, 1, 1, 0},
     {1, 0, 0, 1},
     {0, 1, 1, 0}},

    {{0, 1, 1, 0},
     {1, 0, 0, 1},
     {1, 1, 1, 1},
     {0, 0, 0, 1},
     {1, 1, 1, 0}}
};

void pinMode (uint8_t pin_number, GPIOMode_TypeDef mode) {
    if (pin_number > 15)
        return;

    GPIO_InitTypeDef GPIO_InitStructure = {0};

    RCC_APB2PeriphClockCmd (RCC_APB2Periph_GPIOA | RCC_APB2Periph_GPIOC | RCC_APB2Periph_GPIOD, ENABLE);

    GPIO_InitStructure.GPIO_Pin = pinMap[pin_number].PIN;
    GPIO_InitStructure.GPIO_Mode = mode;
    GPIO_InitStructure.GPIO_Speed = GPIO_Speed_30MHz;

    GPIO_Init (pinMap[pin_number].PORT, &GPIO_InitStructure);
}

void digitalWrite (uint8_t pin_number, uint8_t bit_state) {
    if (pin_number > 15)
        return;
    if (bit_state == 1) {
        GPIO_SetBits (pinMap[pin_number].PORT, pinMap[pin_number].PIN);
    } else {
        GPIO_ResetBits (pinMap[pin_number].PORT, pinMap[pin_number].PIN);
    }
}

uint8_t digitalRead (uint8_t pin_number) {
    if (pin_number > 15)
        return 0;
    return GPIO_ReadInputDataBit (pinMap[pin_number].PORT, pinMap[pin_number].PIN);
}

void updateDisplay (const uint8_t LED_Matrix[5][4], uint32_t duration) {        // runs the display for 'duration' milliseconds
    for (uint32_t it = 0; it < (duration / (DELAY_FRAME * 5)); it++) {
        for (uint8_t c = 0; c < 5; c++) {
            pinMode (c, GPIO_Mode_Out_PP);
            digitalWrite (c, 0);
            for (uint8_t l = 0; l < 5; l++) {
                if (l < c) {
                    if (LED_Matrix[l][c - 1] == 1) {
                        pinMode (l, GPIO_Mode_Out_PP);
                        digitalWrite (l, 1);
                    }
                }
                if (l > c) {
                    if (LED_Matrix[l][c] == 1) {
                        pinMode (l, GPIO_Mode_Out_PP);
                        digitalWrite (l, 1);
                    }
                }
            }
            Delay_Ms (DELAY_FRAME);
            for (uint8_t pin = 0; pin < 5; pin++) {
                pinMode (pin, GPIO_Mode_IN_FLOATING);
            }
        }
    }
}

int main (void) {
    SystemCoreClockUpdate();
    Delay_Init();
    //USART_Printf_Init (115200); // actually the TX pin isn't broken out...
    pinMode(0, GPIO_Mode_IN_FLOATING);
    pinMode(1, GPIO_Mode_IN_FLOATING);
    pinMode(2, GPIO_Mode_IN_FLOATING);
    pinMode(3, GPIO_Mode_IN_FLOATING);
    pinMode(4, GPIO_Mode_IN_FLOATING);
    pinMode (7, GPIO_Mode_Out_PP);
    Delay_Ms (5000);
    //printf ("CH32 devboard ready\r\n"); // actually the TX pin isn't broken out...
    pinMode (BUTTON_PIN, GPIO_Mode_IN_FLOATING);  // Already have external 20k pull up

    while (1) {
        while (digitalRead (BUTTON_PIN) == 1) {
            digitalWrite (LED_PIN, stateLED);
            stateLED = !stateLED;
            Delay_Ms (100);
        }
        for (uint8_t counter = 9; counter > 0; counter--) {  // count down to 0
            updateDisplay (Digits_Matrix[counter], 1000);
        }
        updateDisplay (Off_LED_Matrix, 300);    //
        updateDisplay (Digits_Matrix[0], 300);  // fun blinking animation :D
        updateDisplay (Off_LED_Matrix, 300);    //
        updateDisplay (Digits_Matrix[0], 300);  //
        updateDisplay (Off_LED_Matrix, 300);    //
        digitalWrite (LED_PIN, 1);                  //
        updateDisplay (On_LED_Matrix, 6000);        // lit all LEDs for 6 seconds
        updateDisplay (Off_LED_Matrix, 10);     
    }
}

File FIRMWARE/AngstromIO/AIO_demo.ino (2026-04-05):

/*  AngstromIO mini devboard demo code | by C.G. | https://github.com/Dieu-de-l-elec/AngstromIO-devboard/tree/main
 *  Based on megaTinyCore library by SpenceKonde
 *  
 *  The devboard can be programmed using the Serial UPDI programmer, 
 *    To set up the Attiny1616 in the arduino IDE, the board package has to be installed first (paste http://drazzy.com/package_drazzy.com_index.json in File>Preferences>Additional Board manager URL) 
 *    Then the Attiny1616 can be selected, with "SerialUPDI - 230400" as programmer
 *  The programmer and AIO should be connected to the same USB Host (the AIO has to share ground with the programmer, so all three USB-C connected to the computer)
 *  And when downloading the sketch, a wire (UPDI) would be pressed against the UPDI pad on the AIO (a pogopin would be suited here, but it work without)
 *  
 *  Have fun! :D
 */

#include <tinyNeoPixel.h>
#define PIN            2
#define NUMPIXELS      2

int waitTime = 1000;
int count = 0;
tinyNeoPixel LED = tinyNeoPixel(NUMPIXELS, PIN, NEO_GRB + NEO_KHZ800);

void setup() {
  LED.begin();
  LED.setBrightness(37);
  Serial.begin(9600);
  delay (2000);
}
void loop() {
  Serial.println ("Hi! I'm AngstromIO!");
  LEDTest();
  count += 1;
  Serial.print ("I've been running ");
  Serial.print (count);
  Serial.println (" loops!");
}
void LEDTest () {
  // pixels.Color takes RGB values from 0,0,0 up to 255,255,255
  LED.setPixelColor(0, LED.Color(255, 0, 0)); // RED
  LED.setPixelColor(1, LED.Color(0, 255, 0)); // GREEN
  LED.show();
  delay(waitTime);
  LED.setPixelColor(0, LED.Color(0, 255, 0)); // GREEN
  LED.setPixelColor(1, LED.Color(0, 0, 255)); // BLUE
  LED.show();
  delay(waitTime);
  LED.setPixelColor(0, LED.Color(0, 0, 255)); // BLUE
  LED.setPixelColor(1, LED.Color(255, 0, 0)); // RED
  LED.show();
  delay(waitTime);
  LED.setPixelColor(0, LED.Color(255, 0, 255)); // MAGENTA
  LED.setPixelColor(1, LED.Color(255, 0, 255)); // MAGENTA
  LED.show();
  delay(waitTime);
  LED.setPixelColor(0, LED.Color(255, 255, 0)); // YELLOW
  LED.setPixelColor(1, LED.Color(255, 255, 0)); // YELLOW
  LED.show();
  delay(waitTime);
  LED.setPixelColor(0, LED.Color(0, 255, 255)); // CYAN
  LED.setPixelColor(1, LED.Color(0, 255, 255)); // CYAN
  LED.show();
  delay(waitTime);
  LED.setPixelColor(0, LED.Color(255, 255, 255)); // WHITE
  LED.setPixelColor(1, LED.Color(255, 255, 255)); // WHITE
  LED.show();
  delay(waitTime);
}
